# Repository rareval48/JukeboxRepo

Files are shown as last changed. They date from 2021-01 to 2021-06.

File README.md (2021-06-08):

# JukeboxRepo

This is the repo for Rafael and Paul's Jukebox Project.

<br>

## Table of Contents
* [Overview](#overview)
* [Design](#design)
* [Code Prototype](#code-prototype---paul)
* [Code](#code---paul)
* [CAD Design](#cad-design---rafael-and-paul)
* [Assembly](#assembly---rafael-and-paul)
* [What we would do differently next time](#what-we-would-do-differently-next-time)

<br>

## Additional Documentation
* [Plan](/docs/plan.md)
* [Songs](/docs/songs.md)
* [Component List](/docs/component_list.md)

<br>
<br>

## Overview

Having completed the preliminary CAD and code assignments for Engineering II, the next assignment was to create a **Sensor Robot**. This robot had to be a device which would use some kind of sensor as an input, and use some kind of output which would be affected by the input. There was a certain amount of flexibility with the requirements, so the sensor could just be sensing an input from the user.

For our Sensor Robot, we (Rafael Arevalo and Paul Schakel) decided to create a jukebox. When completed, this jukebox would let the user select songs and add them to a queue which would play them one by one. For more details on our original design and timeline visit our [planning document](docs/plan.md).

<br>

### Tools used

- CAD - [Onshape](https://www.onshape.com/en/)

- Code - [Ardiuno IDE](https://www.arduino.cc/en/software) and [VS Code](https://code.visualstudio.com/)

- Wiring Diagram - [Fritzing](https://fritzing.org/)

- Image Editing - [GIMP](https://www.gimp.org/)

- Minor Video Editing - [Kdenlive](https://kdenlive.org/en/)

<br>
<br>

## Design

Our final product differed greatly from the original concept we came up with, as we completely reworked the user interface and decided to leave some features out. We decided that the best design for the Jukebox would be to have a simple box with holes for the components. However, the particulars of some of the specific designs, such as the user interface, were still up in the air. The original design was going to use four buttons for the user to navigate the menus, but at the suggestion of Mr. Helmstetter, we swapped out three of the buttons for one rotary encoder. The rotary encoder replaced the **next**, **previous**, and **select** buttons with the rotation of the knob and the button within the encoder. 

Comparison of original and final design

Additionally, our original design was going to have a coin slot which the user would use to pay for songs. However, this feature proved too complicated and after one round of attempted prototyping we scrapped the idea.

<br>
<br>

## Code Prototype - Paul

Before going to the trouble of creating all of the menus and other user interface features, we decided to create a prototype to make sure that all the components were functional. While most of the code in the prototype didn't make it to the final code sketch, the displayText() function was complete at this stage, so it was copied over. 

#### displayText Function

```c++
void displayText() {        // This function is responsible for displaying menu text to the screen.
  int lineToScroll;         // It can display up to 2 lines of text, and will scroll each line individually if its length exeeds 16 characters
  String toScroll;
  int length1 = textLine1.length();
  int length2 = textLine2.length();

  lcd.clear();  //clears previous displayed text

  if (length1 > 16 && length2 <= 16) {   //only scrolls line 1 if true
    toScroll = textLine1;
    lineToScroll = 0;
    lcd.setCursor(0, 1);
    lcd.print(textLine2);
  } else if (length1 <= 16 && length2 > 16) {   //only scrolls line 2 if true
    toScroll = textLine2;
    lineToScroll = 1;
    lcd.setCursor(0, 0);
    lcd.print(textLine1);
  } else if (length1 > 16 && length2 > 16) {   //scrolls both lines if true
    lcd.setCursor(scrollCursor, 0);
    lcd.print(textLine1.substring(stringStart, stringStop));
    lcd.setCursor(scrollCursor, 1);
    lcd.print(textLine2.substring(stringStart, stringStop));
    if (length1 > length2) {
      toScroll = textLine1;
      lineToScroll = 0;
    } else {
      toScroll = textLine2;
      lineToScroll = 1;
    }
  } else {   //doesnt scroll either line
    lcd.setCursor(0, 0);
    lcd.print(textLine1);
    lcd.setCursor(0, 1);
    lcd.print(textLine2);
  }

  // general code which scrolls the specified line when only one line is too long
  lcd.setCursor(scrollCursor, lineToScroll);
  lcd.print(toScroll.substring(stringStart, stringStop));

  if (stringStart > stringStop) {   //resets variables, its basically an error checking measure
    stringStart = 0;
    stringStop = 0;
    scrollCursor = 0;
  } if (stringStart == 0 && scrollCursor > 0) {  //shows an additional character when scrolling in from the side
    scrollCursor--;
    stringStop++;
  } else if (stringStart == stringStop) {   //restarts the cycle
    stringStart = stringStop = 0;
    scrollCursor = screenWidth;
  } else if (stringStop == toScroll.length() && scrollCursor == 0) {    //makes the string go off the screen to the right
    stringStart++;
  } else {  //happens if screen is full and keeps text scrolling
    stringStart++;
    stringStop++;
  }
}
```

Basically, this function displays the two lines of text on the LCD screen, scrolling them when neccesary. It does this with three variables: **stringStart**, **stringStop**, and **scrollCursor**. **stringStart** and **stringStop** are used to determine the portion of string which is displayed, because the function is only displaying a portion of the string beginning at the index determined by **stringStart** and ending at the index determined by **stringStop**. The movement of the text is accomplished by **scrollCursor**, so that if only the first 2 characters are being displayed they will be printed at the far right of the screen.

### Links and Images

[Link to Code Prototype](/code_prototyping/code_prototyping.ino)

Short demo video of jukebox prototype (http://www.youtube.com/watch?v=Xu1ld7YbddA "Short demo video of jukebox prototype")

Short demo video of jukebox prototype

### Reflection

The prototype wasn't too difficult since it was just basically just copying code from examples and cobbling it together with some logic. There was a moment where I was concerned that playing music in the background wouldn't work, since I had hooked up the musicPlayer to play the song which was displayed on the LCD screen, and it wasn't playing. However. I soon realized that what my code was actually doing was trying to play the song thousands of times per second, and once I had put in some logic to only play the displayed song when I pressed a button, it worked perfectly.

<br>
<br>

## Code - Paul

The code for this project was rather complex, and the plan which I had created in the [pseudocode](/pseudocode) turned out to be far more complicated than it needed to be. Originally, there were going to be several classes stored within a library called JukeboxUtils. However, once I started running out of SRAM halfway through the making of the code, I realized that I needed to cut some corners to make the program fit on the Arduino. After lots of missteps and malfunctions, I settled on a design which would, instead of using classes, just make each menu a collection of variables tied together within the main loop. I did create one [struct](https://en.wikipedia.org/wiki/Struct_(C_programming_language)) which would contain the information about each song, but all of the other classes were removed.

### Item Storage

In order to keep SRAM usage below critical levels (usually around 80%) I had to use a variety of different approaches to contain the items in each menu. For the genre menu and the main menu, I stored the value of each item (which were char arrays) in program memory, and created an array of those items which was also stored in program memory. To access the items, I stored the current item in a char array stored in SRAM. 

For the song menu, I took a different approach, creating an array of Song structs for each genre, and then using a pointer to access the values in each array. Similarly to my approach for accessing items in the genre and main menus, I used a Song struct stored in SRAM to contain the current item. 

Unfortunately, the approach I used for the song menu was impossible to use again for the queue and the queue menu because the array of songs in the queue had to be able to contain any song which the user selects, in any arrangement. In order to save SRAM, I stored the items in the queue as an array of pointers to Songs. This approach solved the problem nicely, and I could also use the current item approach I used for the song menu in the queue menu.

### Songs

The songs on the jukebox are organized by genre, and then sorted alphabetically by the artist's name within each genre. A list of all of the songs we added can be found [here](/docs/songs.md)

### Links and Images

[Link to Code](/jukebox_code/jukebox_code.ino)

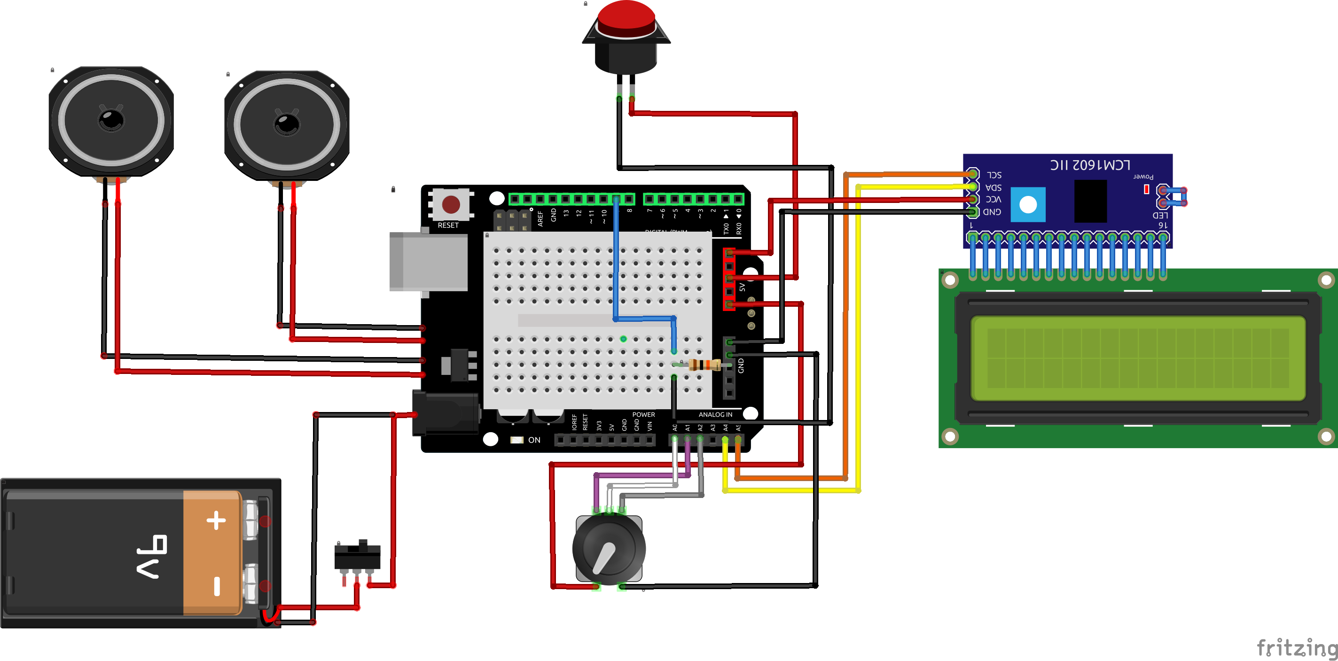
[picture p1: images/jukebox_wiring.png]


Wiring diagram for the Jukebox

Short demo of final jukebox user interface (http://www.youtube.com/watch?v=iKjhCtucQsA "Short demo of final jukebox user interface")

Short demo of jukebox user interface

### Reflection

This was the most complex project I've done in engineering, code wise, and as such I met with a significant number of difficulties while working on it. The greatest difficulty I came across was keeping the program within the tiny constraints of the SRAM of the Arduino. I had to take many steps to optimize the program for low memory usage, which include making functions pass arguments [by reference](https://www.learncpp.com/cpp-tutorial/passing-arguments-by-reference/), using [pointers](https://www.youtube.com/watch?v=rtgwvkaYt1A) to point to data rather than copying the data, using char arrays instead of Strings to reduce heap fragmentation, and using [program memory](https://www.arduino.cc/reference/en/language/variables/utilities/progmem/) to store large pieces of data. Adafruit has a [useful guide](https://learn.adafruit.com/memories-of-an-arduino/optimizing-sram) which details these concepts.

Overall, this project has been very good for my development as a programmer since I got the opportunity to learn a lot more about C++. Towards the end of the project I really began to appreciate the control that C++ gives to the programmer especially with memory allocation. I usually write code which runs on modern systems with plenty of resources, and programming a microcontroller with such limiting constraints forced me to think outside the box. 

<br>
<br>

## CAD Design - Rafael and Paul

Our CAD design was fairly straightforward - a box with holes for the various components. As chronicled in our initial [design](#design) process, we made some changes to the user interface, but eventually settled on the design depicted below, with an LCD screen centered in the upper half of the front panel, and a rotary encoder and a back button to navigate the menus. We also included holes in the sides for the speakers, and small holes to interface with the Aruduino,  charge the battery, and hold in place the power switch.

### Links and Images

[Link to CAD](https://cvilleschools.onshape.com/documents/5302f12635f173b4517b5b74/w/e0544944f1d230a23635893f/e/4d6f8522cf2141e3e206f9b8)

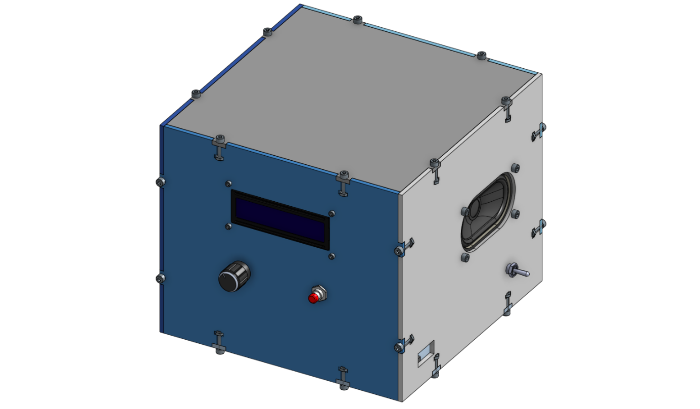
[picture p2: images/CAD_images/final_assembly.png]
Final Assembly


Final Assembly

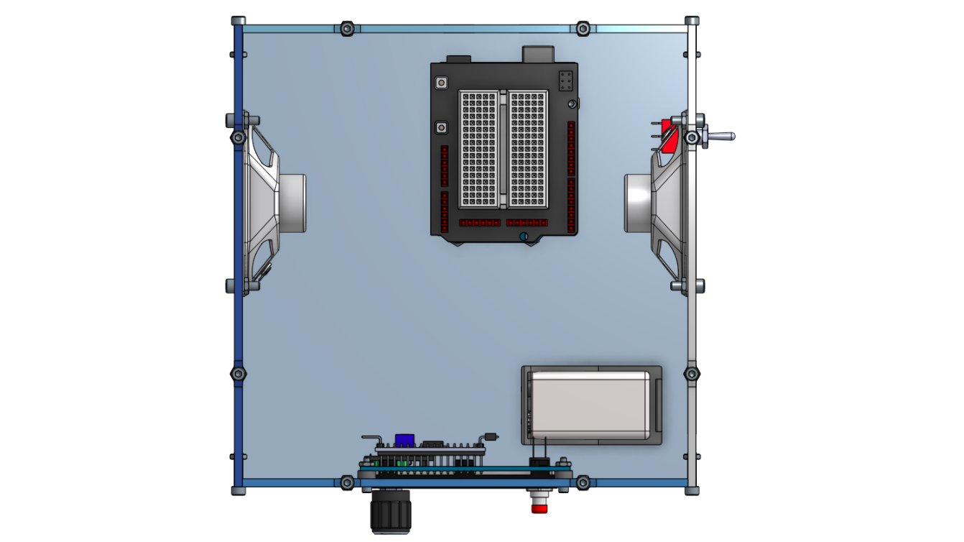
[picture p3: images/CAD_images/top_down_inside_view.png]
Inside View


Inside View

### Reflection

The designing of the actual CAD was fairly simple, but it took us a while because we had to make a lot of revisions and modifications. The hardest part was the tedium of repeatedly inserting screw holes, screws and nuts. We had to make a few major changes to the design over time, as we started with the idea of using friction to hold the box together, but decided to use screws instead so it would be more sturdy. We also originally made the box too small to fit all the parts, so we had to make some significant modifications to accomodate the components.

<br>
<br>

## Assembly - Rafael and Paul

The fabrication and assembly of the Jukebox was the final part of our project. We used a laser cutter to create the sides of our box, and a 3D printer to create several tiny standoffs for the LCD screen. After fabricating our parts, we then installed our various components and assembled the wiring. The list of materials and components in the Jukebox can be found [here](docs/component_list.md).

### Links and Images

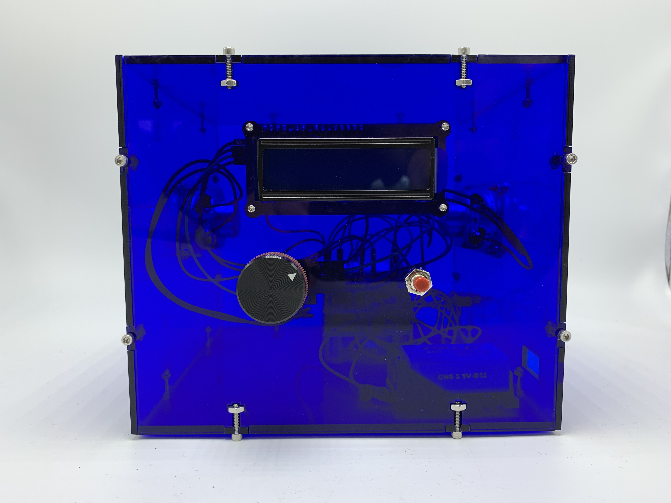
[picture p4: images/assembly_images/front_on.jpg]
Front View


Front View

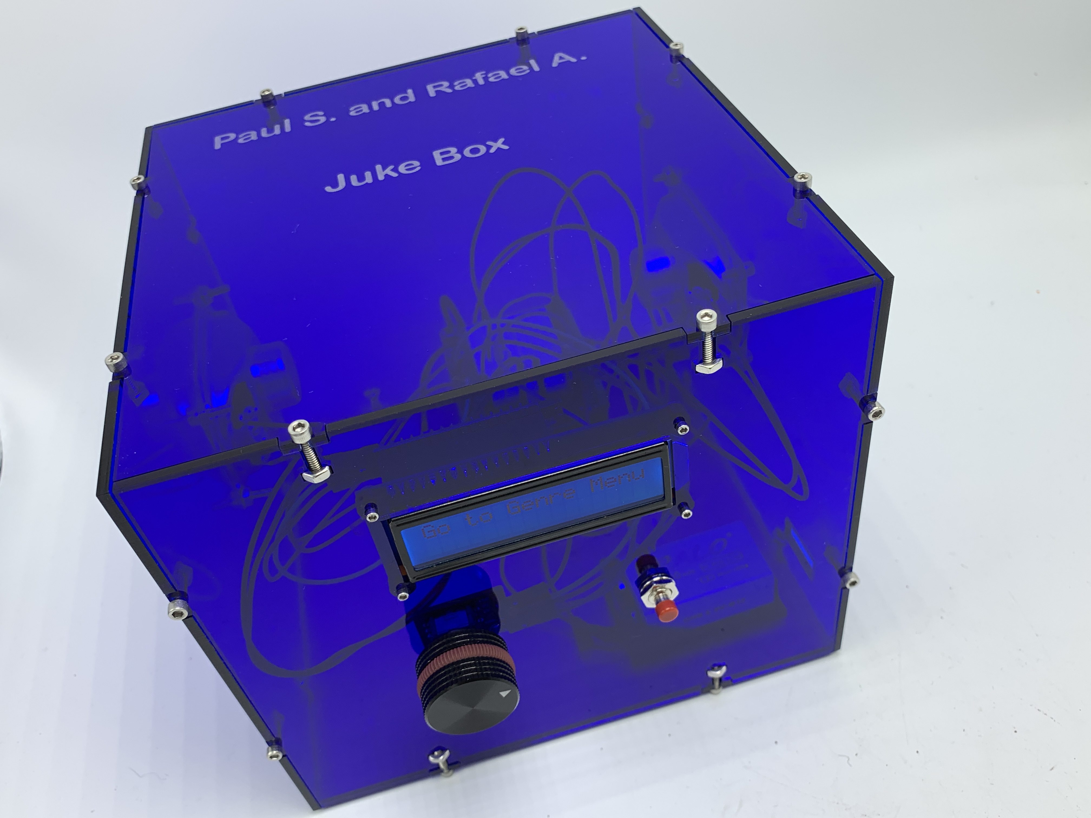
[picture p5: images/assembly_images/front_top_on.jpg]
Front Top View


Front Top View

[Additional Images can be found here](/images/assembly_images/)

### Reflection

The assembly process was fairly simple and straightforward compared to the other parts of the project. However, it wasn't without some missteps. We originally designed the box with the t-hole slots much closer together, which led to several corners breaking off while we were assembling the box. Thankfully, since we designed the box using a set of variables, the issue was easily fixed by changing the value of the TAB_DISTANCE variable. We also ran into an issue with one of the standoffs shorting out a connection on the Arduino which made it unable to recieve USB input or output. We fixed this with a slightly less elegant solution, using electrical tape to protect the circuitry of the Arduino. Overall, the Jukebox project has been an amazing learning experience, and we are both very happy with the result.

<br>
<br>

## What we would do differently next time

We were very happy with our result this time, but if we were to create the Jukebox again, there are a few things we would do differently.

* 3D printing the standoffs for the Arduino
    - One of the metal standoffs shorted out part of USB circuit on the Arduino, we made a quick and dirty fix with electrical tape, but in a redesign we would simply use 3D printed standoffs.
* Better wire management
    - The inside of the Jukebox doesn't look very clean, wiring wise, and that could be improved significantly with some brackets along the edges to tuck wires away nicely.
* Menu redesign
    - The menu as it is right now is functional, but it isn't really very intuitive. If we changed the horizontal scrolling to a vertical scrolling interface, we could make the menu a lot cleaner. Another idea would be to use a larger LCD screen as well, so there would be more room for a vertical menu.
* CAD design methods
    - To create our box, we created each side individually. However, a faster method to create our box would have been to create a solid box that would be the correct dimensions, and base the sides off of that box, deleting the solid box afterward.

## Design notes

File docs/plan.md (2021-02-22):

# Jukebox Project Plan

### Description

The goal of this project is to create a functioning jukebox which will be able to play songs selected by the user. We will know if our problem is solved when a user can successfully navigate through the menus to play 6 songs in a row.

The user will be able to use four buttons to navigate through menus: Next item, Previous item, Previous menu, and Select item. The menus will be displayed on an LCD screen mounted on the front of the box. To select a song, the user will use the buttons to select a genre, and then a song.

The basic design of the jukebox will be a box, with the panels connected with tabs and screws. On each side of the box, there will be a hole for a speaker. On the front of the box, the four buttons and the LCD screen will be mounted in roughly the center. Below is a very rudimentary sketch of the design:

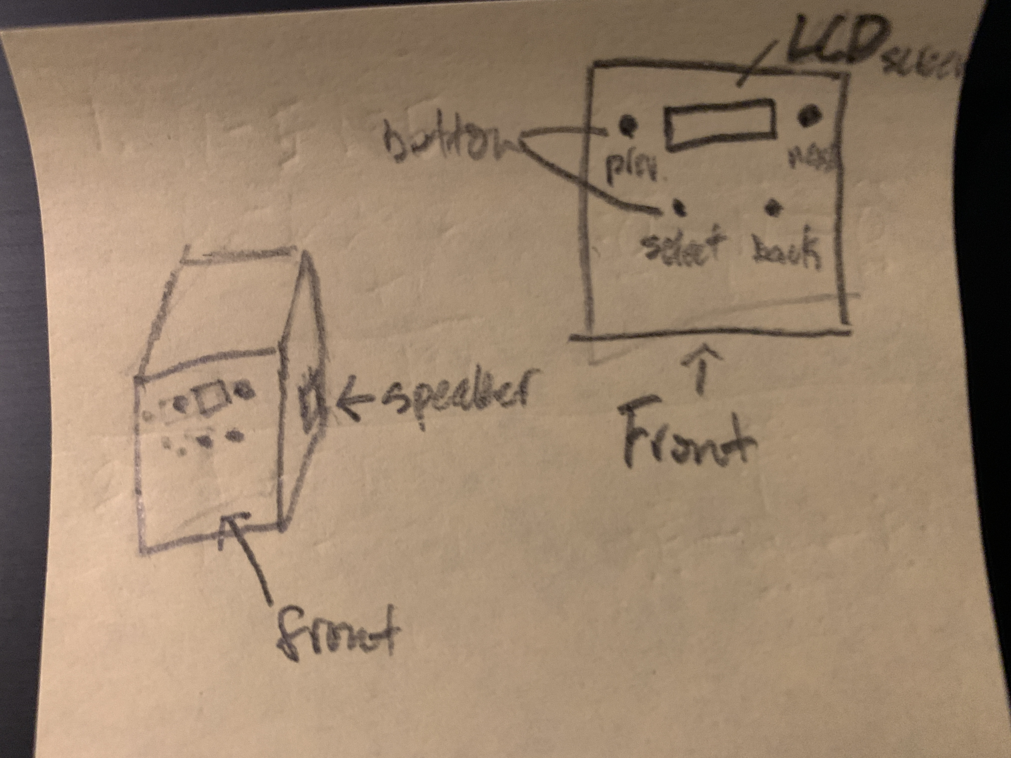
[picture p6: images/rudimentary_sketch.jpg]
Rudimentary Sketch


[Here is a link to the pseudocode directory](/pseudocode)

<br>

### Timeline

* Basic CAD design done: Third week of February

* Code done: Last week of February

* Final CAD design done: First week of March

* Fabrication: Sometime in the second week of March

* Assembly: Third week of March

* Finishing touches: Fourth week of March

* Final Deadline: 03/25/21

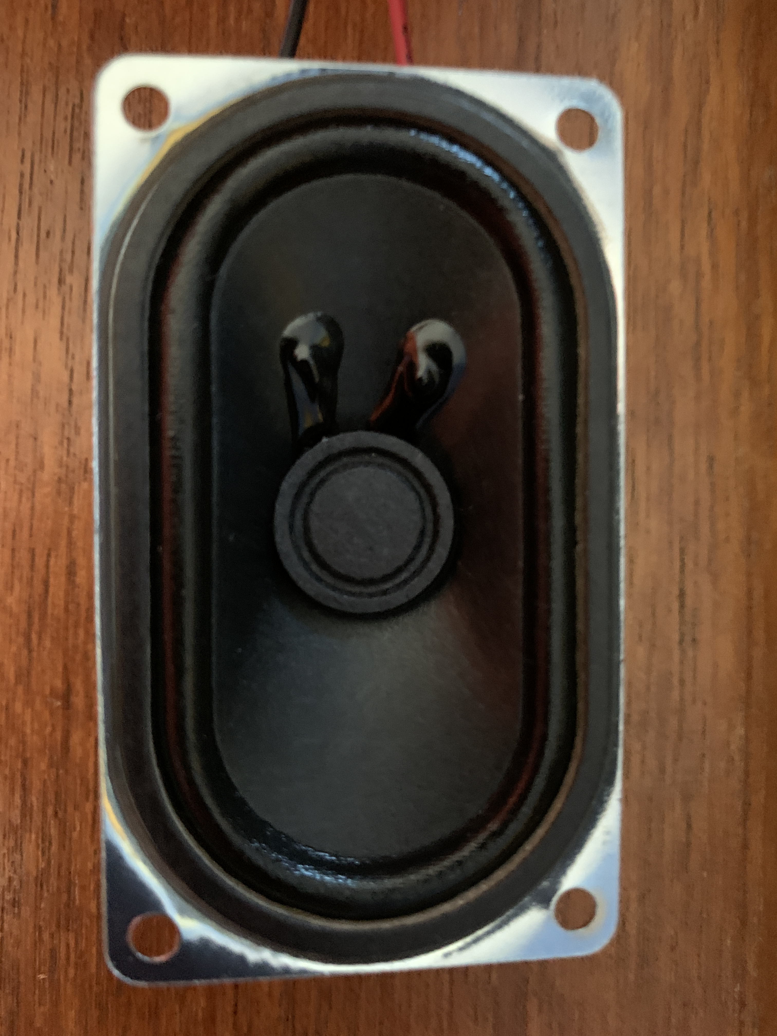
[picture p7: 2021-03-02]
images/speaker.jpg

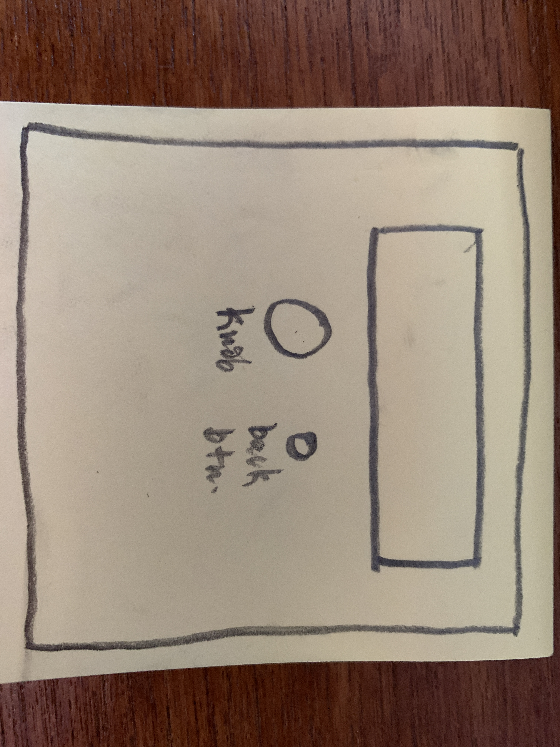
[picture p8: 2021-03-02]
images/new_front_sketch.jpg

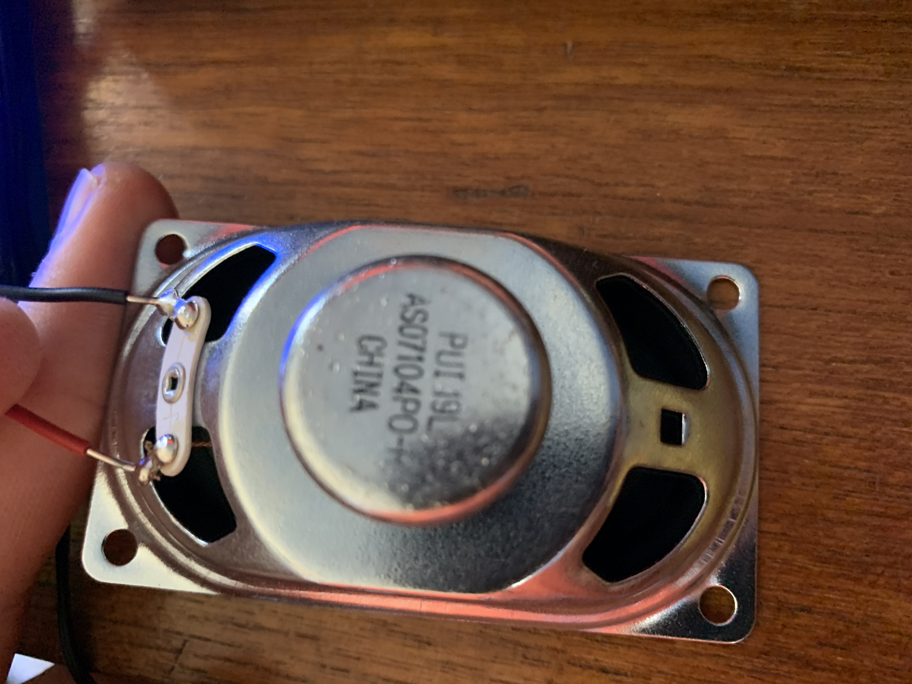
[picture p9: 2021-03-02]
images/back_of_speaker.jpg

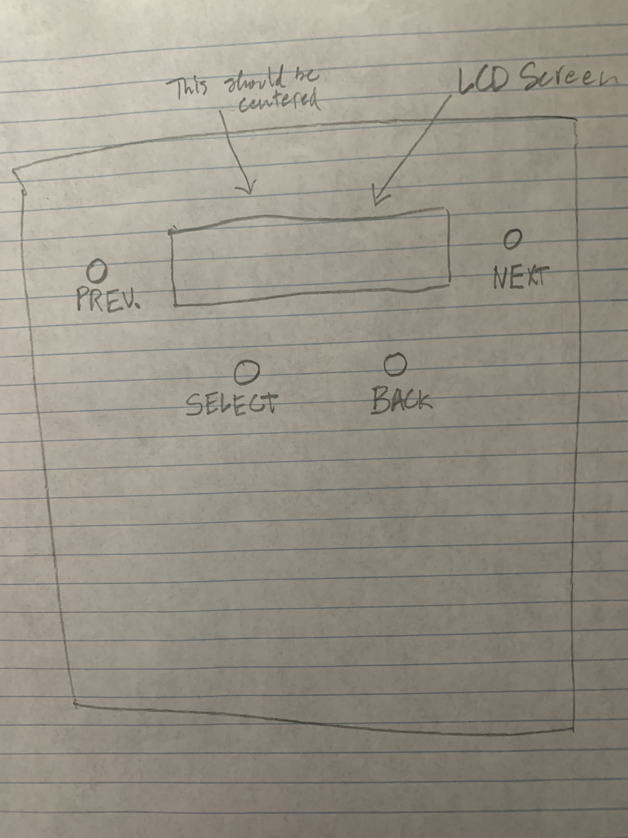
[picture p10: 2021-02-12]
images/front_sketch.jpg

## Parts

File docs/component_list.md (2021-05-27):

# List of Components for Jukebox

<br>

| Item | Quantity |
| --- | --- |
| Arduino Uno | 1 |
| Arduino Prototyping Shield | 1 |
| Adafruit VS1053 mp3 Shield | 1 |
| Rotary Encoder | 1 |
| Encoder Knob | 1 |
| Panel Mount Pushbutton | 1 |
| Mini Breadboard | 1 |
| AS07104PO-R Speaker | 2 |
| SPDT Panel Mount Switch | 1 |
| 16x2 LCD Screen w/ I2C Backpack | 1 |
| 25x.5 Aluminum Hex Standoff | 4 |
| Socket Head Cap Screw 4-40 x 1/2 | 36 |
| Machine Screw Nut 4-40 | 36 |
| Socket Head Cap Screw 1-72 x 3/8 | 7 |
| Machine Screw Nut 1-72 | 7 |
| 9V Battery Holder | 1 |
| Rechargeable 9V Battery | 1 |
| 3D Printed Standoff | 4 |
| Laser-cut Sides | 1 Each |
| Wires | Many |

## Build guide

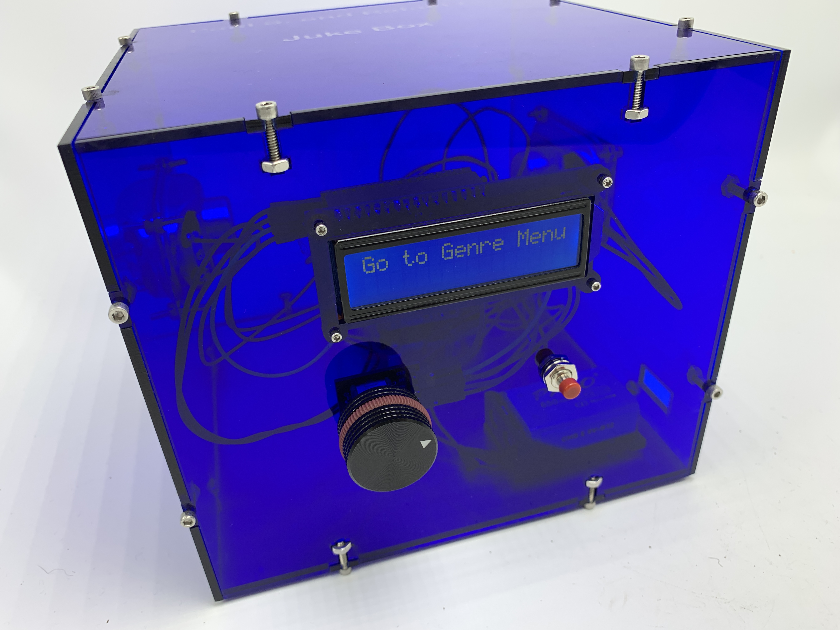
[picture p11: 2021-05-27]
images/assembly_images/front_side_on.jpg

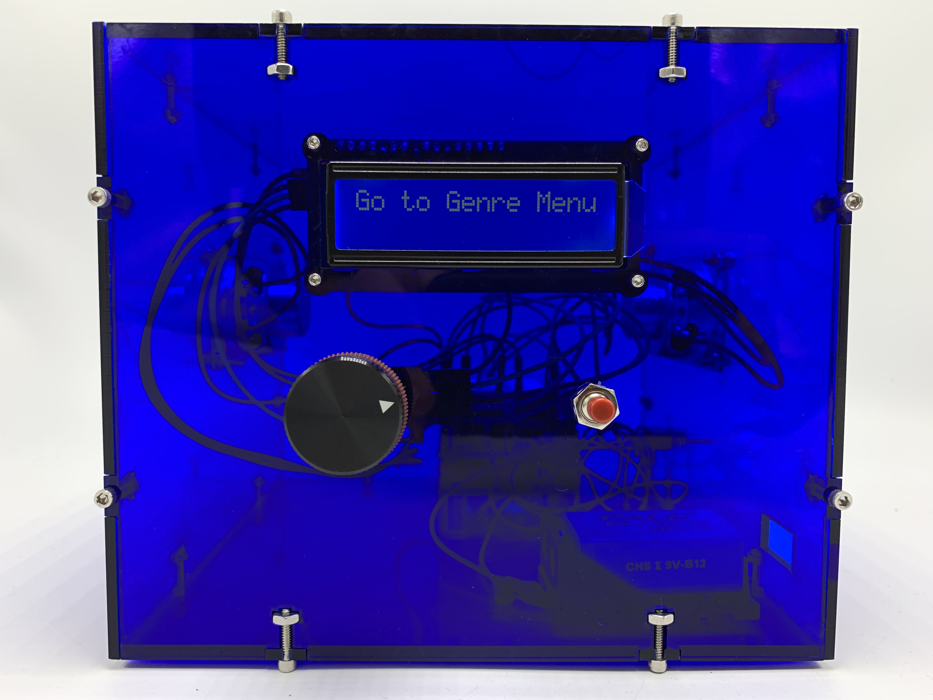
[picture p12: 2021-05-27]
images/assembly_images/front_off.jpg

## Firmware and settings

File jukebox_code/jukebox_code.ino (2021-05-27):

/*

Written by Paul Schakel, March 2021

This is the code for Paul and Rafael's Jukebox project. It implements a full-featured interface for choosing and playing a selection of songs.

More information about the interface and how it works is available here: https://github.com/rareval48/JukeboxRepo#code---paul

*/

#include <SPI.h>
#include <ClickEncoder.h>          //https://github.com/0xPIT/encoder
#include <TimerOne.h>
#include <Adafruit_VS1053.h>       //https://github.com/adafruit/Adafruit_VS1053_Library
#include <LiquidCrystal_I2C.h>     //https://github.com/johnrickman/LiquidCrystal_I2C
#include <MemoryFree.h>            //https://github.com/mpflaga/Arduino-MemoryFree

// These are the pins used for the music maker shield
#define SHIELD_RESET  -1      // VS1053 reset pin
#define SHIELD_CS     7      // VS1053 chip select pin (output)
#define SHIELD_DCS    6      // VS1053 Data/command select pin (output)
#define CARDCS 4     // Card chip select pin
#define DREQ 3       // VS1053 Data request, ideally an Interrupt pin

#define BACK_BUTTON_PIN 9

// These are the different menu states which are possible
#define MAIN_MENU 0
#define QUEUE_MENU 1
#define GENRE_MENU 2
#define SONG_MENU 3
#define HIDDEN_MENU 4

//set maximums
#define MAX_QUEUE_LENGTH 12
#define MAX_STRING_LENGTH 36
#define SHORTER_STRING_LENGTH 15

//define structure datatypes
struct Song {
  char title[MAX_STRING_LENGTH];
  char filename[SHORTER_STRING_LENGTH - 1];
  char artist[SHORTER_STRING_LENGTH + 3];
};


struct genreListInfo {  //used for creating songMenus
  Song *genreList;
  uint8_t length;
};


Adafruit_VS1053_FilePlayer musicPlayer = Adafruit_VS1053_FilePlayer(SHIELD_RESET, SHIELD_CS, SHIELD_DCS, DREQ, CARDCS);

LiquidCrystal_I2C lcd(0x3F, 16, 2);  // set the LCD address to 0x27 for a 16 chars and 2 line display

ClickEncoder *encoder;
int16_t last;

void timerIsr() {   //used by the ClickEncoder
  encoder->service();
}

int backButtonState;

//used for text scrolling in displayText()
uint8_t screenWidth = 16;
uint8_t screenHeight = 2;
uint8_t stringStart = 0;
uint8_t stringStop = screenWidth;
uint8_t scrollCursor = 0;

//these two variables set what is displayed on the lcd screen, they are set by setDisplayText
String textLine1 = "";
String textLine2 = "";

//keep track of time
unsigned long clock;
unsigned long clockPrev;  //needed to check if a specific moment in time has passed

int encoderValue = 0;
int encoderValuePrev = 0;  //used to check if encoderValue went up or down
int encoderValueChange = 0;
bool encoderChangeDetected = false;
long timeChangeDetected = 0;

int menuState = MAIN_MENU;

bool hiddenMenuTrigger = false;   //used to enter the hidden menu
bool canEditQueue = false;  //feature which can be activated in hidden menu

//create genreLists
const Song rockList[] PROGMEM =
{
  {"Brothers In Arms", "/track014.mp3", "Dire Straits"},
  {"Money For Nothing", "/track001.mp3", "Dire Straits"},
  {"Sultans Of Swing", "/track015.mp3", "Dire Straits"},
  {"DREAM", "/track021.mp3", "Ocean Grove"},
  {"No Line On The Horizon", "/track008.mp3", "U2"},
  {"Where The Streets Have No Name", "/track005.mp3", "U2"},
  {"With Or Without You", "/track031.mp3", "U2"},
};

const Song metalList[] PROGMEM =
{
  {"Live Or Die", "/track009.mp3", "Apocalyptica"},
  {"Hail To The King", "/track033.mp3", "Avenged Sevenfold"},
  {"Pull Me Under", "/track004.mp3", "Dream Theater"},
  {"Hallowed Be Thy Name", "/track017.mp3", "Iron Maiden"},
  {"Surfing with the Alien", "/track025.mp3", "Joe Satriani"},
  {"Peace Sells", "/track022.mp3", "Megadeth"},
  {"Symphony Of Destruction", "/track026.mp3", "Megadeth"},
  {"Washington Is Next!", "/track028.mp3", "Megadeth"},
  {"Fade To Black", "/track003.mp3", "Metallica"},
  {"Mr. Crowley", "/track007.mp3", "Ozzy Osbourne"},
  {"Hearts Of Iron", "/track018.mp3", "Sabaton"},
  {"Toxicity", "/track027.mp3", "System Of A Down"},
};

const Song jazzList[] PROGMEM =
{
  {"Pittsburgh", "/track023.mp3", "Ahmad Jamal"},
  {"Take Five", "/track012.mp3", "Dave Brubeck"},
  {"In A Sentimental Mood", "/track016.mp3", "Duke Ellington"},
  {"Blue In Green", "/track002.mp3", "Miles Davis"},
  {"So What", "/track020.mp3", "Miles Davis"},
  {"'Round Midnight", "/track024.mp3", "Thelonious Monk"},
};

const Song popList[] PROGMEM =
{
  {"Baby Shark", "/track038.mp3", "Pinkfong"},  //this is a rickroll
};

const Song classicalList[] PROGMEM =
{
  {"Hungarian Dance No. 5", "/track010.mp3", "Brahms"},
  {"Claire de Lune", "/track011.mp3", "Debussy"},
  {"Soviet National Anthem", "/track037.mp3", "Red Army Choir"},
  {"Danse Macabre", "/track006.mp3", "Saint-Saens"},
  {"Blue Danube Waltz", "/track039.mp3", "Strauss"},
  {"1812 Overture", "/track032.mp3", "Tchaikovsky"},
};

const Song rapList[] PROGMEM =
{
  {"My Name Is", "/track041.mp3", "Eminem"},
  {"Just Lose It", "/track042.mp3", "Eminem"},
  {"Hey Ya!", "/track043.mp3", "OutKast"},
  {"Rosa Parks", "/track044.mp3", "OutKast"},
};

const Song electronicList[] PROGMEM =
{
  {"Harder, Better, Faster, Stronger", "/track034.mp3", "Daft Punk"},
  {"SATRN", "/track013.mp3", "deadmau5"},
  {"Strobe", "/track035.mp3", "deadmau5"},
  {"Resonance", "/track029.mp3", "Home"},
  {"Pacific Coast Highway", "/track036.mp3", "Kavinsky"},
  {"66 Mhz", "/track030.mp3", "Waveshaper"},
  {"Spectrum", "/track040.mp3", "Zedd"},
};

//create mainMenu
const char mainMenuItem0[] PROGMEM = "Go to Genre Menu";
const char mainMenuItem1[] PROGMEM = "Go to Queue";
const char *const mainMenuItems[] PROGMEM = {mainMenuItem0, mainMenuItem1};
uint8_t mainMenuCurrentIndex = 0;

//create queue
Song *queue[MAX_QUEUE_LENGTH] = {};
uint8_t queueMenuCurrentIndex = 0;
uint8_t queueMenuCurrentLength = 0;
bool queueEmptyAlert = false;
bool wasPlaying = false;

//create genreMenu
const char genre0[] PROGMEM = "Heavy Metal";
const char genre1[] PROGMEM = "Rock";
const char genre2[] PROGMEM = "Pop";
const char genre3[] PROGMEM = "Jazz";
const char genre4[] PROGMEM = "Classical";
const char genre5[] PROGMEM = "Hip Hop/Rap";
const char genre6[] PROGMEM = "Electronic";
const char *const genreMenuItems[] PROGMEM = {genre0, genre1, genre2, genre3, genre4, genre5, genre6};
uint8_t genreMenuCurrentIndex = 0;
const genreListInfo genreLists[] PROGMEM =    //used for creating new songMenus
{
  {metalList, sizeof(metalList) / sizeof(Song)},
  {rockList, sizeof(rockList) / sizeof(Song)},
  {popList, sizeof(popList) / sizeof(Song)},
  {jazzList, sizeof(jazzList) / sizeof(Song)},
  {classicalList, sizeof(classicalList) / sizeof(Song)},
  {rapList, sizeof(rapList) / sizeof(Song)},
  {electronicList, sizeof(electronicList) / sizeof(Song)},
};

//create songMenu
Song *songMenuPtr;
uint8_t songMenuCurrentIndex = 0;
uint8_t songMenuListLength = 0;

//create hiddenMenu
const char hiddenMenuItem0[] PROGMEM = "Pause/Play";
const char hiddenMenuItem1[] PROGMEM = "Skip Song";
const char hiddenMenuItem2[] PROGMEM = "Edit Queue";
const char hiddenMenuItem3[] PROGMEM = "Clear Queue";
const char *const hiddenMenuItems[] PROGMEM = {hiddenMenuItem0, hiddenMenuItem1, hiddenMenuItem2, hiddenMenuItem3};
uint8_t hiddenMenuCurrentIndex = 0;

//create large SRAM variables
char stringSRAM[MAX_STRING_LENGTH];
char menuCurrentItemString[MAX_STRING_LENGTH];
Song menuCurrentItemSong;

void setup() {
  Serial.begin(9600);

  pinMode(BACK_BUTTON_PIN, INPUT);  //set up back button

  //set current item for main menu
  strcpy_P(menuCurrentItemString, (char *)pgm_read_word(&(mainMenuItems[0])));

  lcd.init();   // initialise the lcd
  lcd.backlight();

  //reserve space for manipulating these strings -- reduces heap fragmentation
  textLine1.reserve(MAX_STRING_LENGTH + 5);
  textLine2.reserve(MAX_STRING_LENGTH);

  encoder = new ClickEncoder(A1, A0, A2);
  encoder->setAccelerationEnabled(false);

  Timer1.initialize(1000);
  Timer1.attachInterrupt(timerIsr);
  last = -1;

  if (! musicPlayer.begin()) { // initialise the music player
    Serial.println(F("Couldn't find VS1053, do you have the right pins defined?"));
    while (1);
  }
  Serial.println(F("VS1053 found"));

  if (!SD.begin(CARDCS)) {  //initialise SD card
    Serial.println(F("SD failed, or not present"));
    while (1);  // don't do anything more
  }

  musicPlayer.setVolume(30, 30);
  musicPlayer.useInterrupt(VS1053_FILEPLAYER_TIMER0_INT);   //lets it play in the background

  Serial.println(freeMemory());
}


void loop() {
  //keep track of timings for LCD scrolling and reading rotary encoder values
  clockPrev = clock;
  clock = millis();

  //get state of back button
  backButtonState = digitalRead(BACK_BUTTON_PIN);

  //manage rotary encoder
  encoderValue += encoder->getValue();
  ClickEncoder::Button encoderButton = encoder->getButton();

  if (encoderValue != encoderValuePrev && !encoderChangeDetected) { //checks if the encoder value has changed, but only if it hasn't detected any change recently
    encoderChangeDetected = true;
    Serial.println(F("change detected"));
    timeChangeDetected = clock;
  }

  if (encoderChangeDetected && clock - timeChangeDetected >= 200 && clockPrev - timeChangeDetected < 200) {   //adds delay for the rotary encoder to stop turning, then checks which direction it turned
    if (encoderValuePrev < encoderValue) {
      encoderValueChange = 1;
    } else if (encoderValuePrev > encoderValue) {
      encoderValueChange = -1;
    }
    Serial.print(F("EncoderValueChange: "));
    Serial.println(encoderValueChange);
    encoderValuePrev = encoderValue;
    encoderChangeDetected = false;
  }

  if (encoderValue != last) {
    last = encoderValue;
    Serial.print(F("Encoder Value: "));
    Serial.println(encoderValue);
  }

  if (clock % 390 <= 100 && clockPrev % 390 > 100) {  //scrolls the text twice a second
    displayText();
  }

  //handle playing of songs
  if (musicPlayer.stopped()) {
    if (queueEmptyAlert) {
      lcd.clear();
      lcd.setCursor(0, 0);
      lcd.print(F("Queue Empty"));
      lcd.setCursor(0, 1);
      lcd.print(F("Add more songs"));
      delay(2000);
      queueEmptyAlert = false;
      wasPlaying = false;
    } if (wasPlaying) {   //removes the first item from the queue and shifts all the other items forward to fill the gap
      Song *newQueue[queueMenuCurrentLength];
      for (uint8_t i = 1; i < queueMenuCurrentLength; i++) {
        newQueue[i - 1] = queue[i];
      }
      queueMenuCurrentLength -= 1;
      memcpy(&queue, &newQueue, sizeof(newQueue));

      if (queueMenuCurrentLength == 0) {
        queueEmptyAlert = true;
      }
    } if (queueMenuCurrentLength > 0) {
      memcpy_P(&menuCurrentItemSong, queue[0], sizeof(Song));

      musicPlayer.startPlayingFile(menuCurrentItemSong.filename);
      wasPlaying = true;
    }
  }

  if (menuState == MAIN_MENU) {   //logic for the mainMenu
    setDisplayText(menuCurrentItemString, "");

    if (encoderValueChange != 0) {  //if the rotary encoder has been turned, changes the current menu item based on which direction it was turned
      uint8_t itemLen = sizeof(mainMenuItems) / sizeof(mainMenuItems[0]);
      if (mainMenuCurrentIndex + 1 >= itemLen && encoderValueChange == 1) { //set current item to first element if previous element was the last and change is +1
        mainMenuCurrentIndex = 0;
      } else if (mainMenuCurrentIndex <= 0 && encoderValueChange == -1) { //set the current item to last element if previous element was the first and change is -1
        mainMenuCurrentIndex = itemLen - 1;
      } else {  //set the current item based on the value of encoderValueChange
        mainMenuCurrentIndex += encoderValueChange;
      }

      strcpy_P(menuCurrentItemString, (char *)pgm_read_word(&(mainMenuItems[mainMenuCurrentIndex]))); //copy the current item into SRAM

      encoderValueChange = 0;
    }

    if (encoderButton != ClickEncoder::Open) {
      switch (encoderButton) {
        case ClickEncoder::Clicked:
          Serial.println(F("Button Clicked"));

          if (strcmpProgmem(menuCurrentItemString, &(mainMenuItems[0]))) {
            menuState = GENRE_MENU;
            strcpy_P(menuCurrentItemString, (char *)pgm_read_word(&(genreMenuItems[genreMenuCurrentIndex]))); //set the current item for genre menu
            Serial.println(F("menu is now genreMenu"));
          }

          if (strcmpProgmem(menuCurrentItemString, &(mainMenuItems[1]))) {
            menuState = QUEUE_MENU;
            memcpy_P(&menuCurrentItemSong, queue[0], sizeof(Song));  //set the current item for queue menu
            Serial.println(F("menu is now queueMenu"));
          }
          break;
      }
    }
  } //end mainMenu logic

  else if (menuState == GENRE_MENU) {   //logic for genreMenu
    setDisplayText(menuCurrentItemString, "");

    if (encoderValueChange != 0) {  //if the rotary encoder has been turned, changes the current item based on which direction it was turned
      uint8_t itemLen = sizeof(genreMenuItems) / sizeof(genreMenuItems[0]);
      if (genreMenuCurrentIndex + 1 >= itemLen && encoderValueChange == 1) { //set current item to first element if previous element was the last and change is +1
        genreMenuCurrentIndex = 0;
      } else if (genreMenuCurrentIndex <= 0 && encoderValueChange == -1) { //set the current item to last element if previous element was the first and change is -1
        genreMenuCurrentIndex = itemLen - 1;
      } else {  //set the current item based on the value of encoderValueChange
        genreMenuCurrentIndex += encoderValueChange;
      }

      strcpy_P(menuCurrentItemString, (char *)pgm_read_word(&(genreMenuItems[genreMenuCurrentIndex]))); //copy the current item into SRAM

      encoderValueChange = 0;
    }

    if (encoderButton != ClickEncoder::Open) {
      switch (encoderButton) {
        case ClickEncoder::Clicked:
          Serial.println(F("Button Clicked"));
          menuState = SONG_MENU;
          
          //checks the current item in the genre menu against each genre, and then sets the song menu pointer to the first element of the list for the selected genre
          for (int i = 0; i < sizeof(genreMenuItems) / sizeof(genreMenuItems[0]); i++) {
            if (strcmpProgmem(menuCurrentItemString, &(genreMenuItems[i]))) {
              songMenuPtr = pgm_read_word(&(genreLists[i].genreList));    //read data out of progmem
              songMenuListLength = pgm_read_word(&(genreLists[i].length));  //same thing here
            }
          }

          memcpy_P(&menuCurrentItemSong, songMenuPtr, sizeof(Song));  //set current item for song menu
          songMenuCurrentIndex = 0;
          break;
      }
    }

    if (backButtonState == HIGH) {  //go back to mainMenu
      menuState = MAIN_MENU;
      strcpy_P(menuCurrentItemString, (char *)pgm_read_word(&(mainMenuItems[mainMenuCurrentIndex]))); //set current item for main menu
      Serial.println(F("back button pressed"));
    }

  }   //end genreMenu logic

  else if (menuState == SONG_MENU) {    //logic for songMenu
    setDisplayText(menuCurrentItemSong.title, menuCurrentItemSong.artist);

    if (encoderValueChange != 0) {  //if the rotary encoder has been turned, changes the current item based on which direction it was turned
      if (songMenuCurrentIndex + 1 >= songMenuListLength && encoderValueChange == 1) { //set current item to first element if previous element was the last and change is +1
        songMenuCurrentIndex = 0;
      } else if (songMenuCurrentIndex <= 0 && encoderValueChange == -1) { //set the current item to last element if previous element was the first and change is -1
        songMenuCurrentIndex = songMenuListLength - 1;
      } else {  //set the current item based on the value of encoderValueChange
        songMenuCurrentIndex += encoderValueChange;
      }

      memcpy_P(&menuCurrentItemSong, songMenuPtr + songMenuCurrentIndex, sizeof(Song)); //copy the current item into SRAM

      encoderValueChange = 0;
    }

    if (encoderButton != ClickEncoder::Open) {
      switch (encoderButton) {
        case ClickEncoder::Clicked:
          Serial.println(F("Button Clicked"));

          if (queueMenuCurrentLength < MAX_QUEUE_LENGTH) {  //if queue isnt full, adds the displayed song to queue
            queue[queueMenuCurrentLength] = songMenuPtr + songMenuCurrentIndex; //add new song to last index
            queueMenuCurrentLength += 1;
            menuState = MAIN_MENU;
            strcpy_P(menuCurrentItemString, (char *)pgm_read_word(&(mainMenuItems[mainMenuCurrentIndex]))); //set current item for main menu
            if (musicPlayer.paused() && queueMenuCurrentLength == 0) {  //starts playing the song if playback is paused and there isn't any additional song in the queue
              memcpy_P(&menuCurrentItemSong, queue[0], sizeof(Song));

              musicPlayer.startPlayingFile(menuCurrentItemSong.filename);
              wasPlaying = true;
            }
            lcd.clear();
            lcd.setCursor(0, 0);
            lcd.print(F("Song Added"));
            delay(1500);
          } else {    //queue is full
            lcd.clear();
            lcd.setCursor(0, 0);
            lcd.print(F("Queue full"));
            lcd.setCursor(0, 1);
            lcd.print(F("Let song end"));
            delay(2000);
          }
          break;
      }
    }

    if (backButtonState == HIGH) {  //go back to genreMenu
      menuState = GENRE_MENU;
      strcpy_P(menuCurrentItemString, (char *)pgm_read_word(&(genreMenuItems[genreMenuCurrentIndex]))); //set the current item for genre menu
      delay(500);   //makes sure that the back button isn't triggered in the genreMenu as well
    }
  }   //end songMenu logic

  else if (menuState == QUEUE_MENU) {   //logic for queueMenu
    if (queueMenuCurrentLength == 0) {
      setDisplayText(F("Queue Empty"), F("Add more songs"));
    } else {
      sprintf(stringSRAM, "%i. %s", queueMenuCurrentIndex + 1, menuCurrentItemSong.title);  //add position in queue

      setDisplayText(stringSRAM, menuCurrentItemSong.artist);

      if (encoderValueChange != 0) {  //if the rotary encoder has been turned, changes the current item based on which direction it was turned
        if (queueMenuCurrentIndex + 1 >= queueMenuCurrentLength && encoderValueChange == 1) { //set current item to first element if previous element was the last and change is +1
          queueMenuCurrentIndex = 0;
        } else if (queueMenuCurrentIndex <= 0 && encoderValueChange == -1) { //set the current item to last element if previous element was the first and change is -1
          queueMenuCurrentIndex = queueMenuCurrentLength - 1;
        } else {  //set the current item based on the value of encoderValueChange
          queueMenuCurrentIndex += encoderValueChange;
        }

        memcpy_P(&menuCurrentItemSong, queue[queueMenuCurrentIndex], sizeof(Song)); //copy the current item into SRAM

        encoderValueChange = 0;
      }
    }

    if (encoderButton != ClickEncoder::Open) {
      switch (encoderButton) {
        case ClickEncoder::Clicked:
          Serial.println(F("Button Clicked"));
          if (canEditQueue) {
            Song *newQueue[queueMenuCurrentLength];
            for (uint8_t i = 0; i < queueMenuCurrentLength; i++) {
              if (i == queueMenuCurrentIndex) {
                continue;
              } else if (i > queueMenuCurrentIndex) {
                newQueue[i - 1] = queue[i];
              } else {
                newQueue[i] = queue[i];
              }
            }
            queueMenuCurrentLength -= 1;
            memcpy(&queue, &newQueue, sizeof(newQueue));

            if (queueMenuCurrentIndex == 0) { //stops playing if the first song in the queue was removed (the song which was playing)
              musicPlayer.stopPlaying();
              wasPlaying = false;   //makes sure there isn't a double skip
            }

            queueMenuCurrentIndex = 0;
            memcpy_P(&menuCurrentItemSong, queue[queueMenuCurrentIndex], sizeof(Song)); //copy the current item into SRAM

            lcd.clear();
            lcd.setCursor(0, 0);
            lcd.print(F("Removed Song"));
            delay(1500);
          }
          break;
        
        case ClickEncoder::Held:
          Serial.println(F("Button Held"));

          if (!hiddenMenuTrigger) {
            hiddenMenuTrigger = true;
          } else {
            hiddenMenuTrigger = false;
          }
          delay(1000); //otherwise it just gets triggered repeatedly
          break;

        case ClickEncoder::DoubleClicked:
          Serial.println(F("Button DoubleClicked"));

          if (hiddenMenuTrigger) {
            menuState = HIDDEN_MENU;
            hiddenMenuTrigger = false;
            canEditQueue = false;
            strcpy_P(menuCurrentItemString, (char *)pgm_read_word(&(hiddenMenuItems[hiddenMenuCurrentIndex]))); //set current item for hidden menu
            Serial.println(F("Entered Hidden Menu"));
          }
          break;
      }
    }

    if (backButtonState == HIGH) {  //go back to mainMenu
      menuState = MAIN_MENU;
      hiddenMenuTrigger = false; //reset trigger
      canEditQueue = false;
      strcpy_P(menuCurrentItemString, (char *)pgm_read_word(&(mainMenuItems[mainMenuCurrentIndex]))); //set current item for main menu
      Serial.println(F("back button pressed"));
    }
  }   //end queueMenu logic

  else if (menuState == HIDDEN_MENU) {    //logic for hidden menu -- used to pause/play playback, play next song, and clear and edit the queue
    setDisplayText(menuCurrentItemString, "");
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

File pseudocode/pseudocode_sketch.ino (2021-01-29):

//include library containing classes for project (song class, menu class)

//selectButton = ?
//previousMenuButton = ?
//nextButton = ?
//previousButton = ?

//create list of all song genres
//create list of all of the songs on the SD card

//Menu *currentMenu = &GenreMenu(genreList)

void setup() {
	Serial.begin(9600);

	//begin musicPlayer
	//begin sd card
}

void loop() {
	//currentMenu.display()
	
	//if nextButton: currentMenu.nextItem()
	//if previousButton: currentMenu.previousItem()
	//if previousMenuButton: 
		//if currentMenu.datatype == SongMenu:

	//if selectButton: 
		//if currentMenu.datatype == SongMenu: 
			//currentMenu.playCurrentSong()
			//Genre
		//else if currentMenu.datatype == GenreMenu:
			//currentMenu = currentMenu.createSongMenu()
}

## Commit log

2021-02-02 Create Jukebox CAD
2021-02-18 Add code for some functionality of rotary encoder and finish displayText() function
2021-02-22 Finished prototype of jukebox
2021-03-02 Add current version of library and sketch - library is basically complete and the sketch has a ways to go
2021-03-02 Add wiring
    [wiring.fzz]
2021-03-02 Update wiring diagram
    [wiring.fzz]
2021-03-02 Add engineering notebook entry for code prototype and fix an incorrect LCD assignment
    [code_prototyping.ino]
2021-03-09 Checkpoint commit so I can clean up the code - memory problems are under control for now thanks to PROGMEM and a more simplified approach, also the rotary encoder gives a reliable output now
    [jukebox_code.ino]
2021-03-12 Update wiring for button to use correct resistor and pin
    [wiring.fzz]
2021-03-16 Add image comparing designs, and relocate documents used to create images to a new directory
    [wiring.fzz]
2021-03-16 Make a couple changes to prototype code for demo video
2021-03-16 Add documentation for code and add a demo video for the code prototype as well as a bit of reorganizing
2021-03-26 Added the bottom for CAD
2021-03-30 Fix bugs and optimize for readability and a bit more efficiency
    [jukebox_code.ino]
2021-05-11 Add new images of CAD
2021-05-11 Update Engineering notebook entry for CAD Design
2021-05-13 Fix the blinking screen when scrolling is not neccessary
    [jukebox_code.ino]
2021-05-27 Add images and engineering notebook entry for final assembly
